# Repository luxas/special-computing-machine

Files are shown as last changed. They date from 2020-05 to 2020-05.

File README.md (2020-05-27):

# special-computing-machine
Let's make a Raspberry Pi cluster similar to real data centers!

# 3D models
The 3D model files in [hardware/models](hardware/models) include the following models by external authors, licensed for non-commercial use from [GrabCAD](https://grabcad.com).

 - [Raspberry Pi 4 Model B](https://grabcad.com/library/raspberry-pi-4-model-b-1) by [Hasanain Shuja](https://grabcad.com/hasanain.shuja-1)
 - [Intel 2.5" SSD 520 Series](https://grabcad.com/library/intel-2-5-ssd-520-series-1) by [Kevin Yu](https://grabcad.com/kevin.yu-7)

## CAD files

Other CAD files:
hardware/models/CU_Tray.step

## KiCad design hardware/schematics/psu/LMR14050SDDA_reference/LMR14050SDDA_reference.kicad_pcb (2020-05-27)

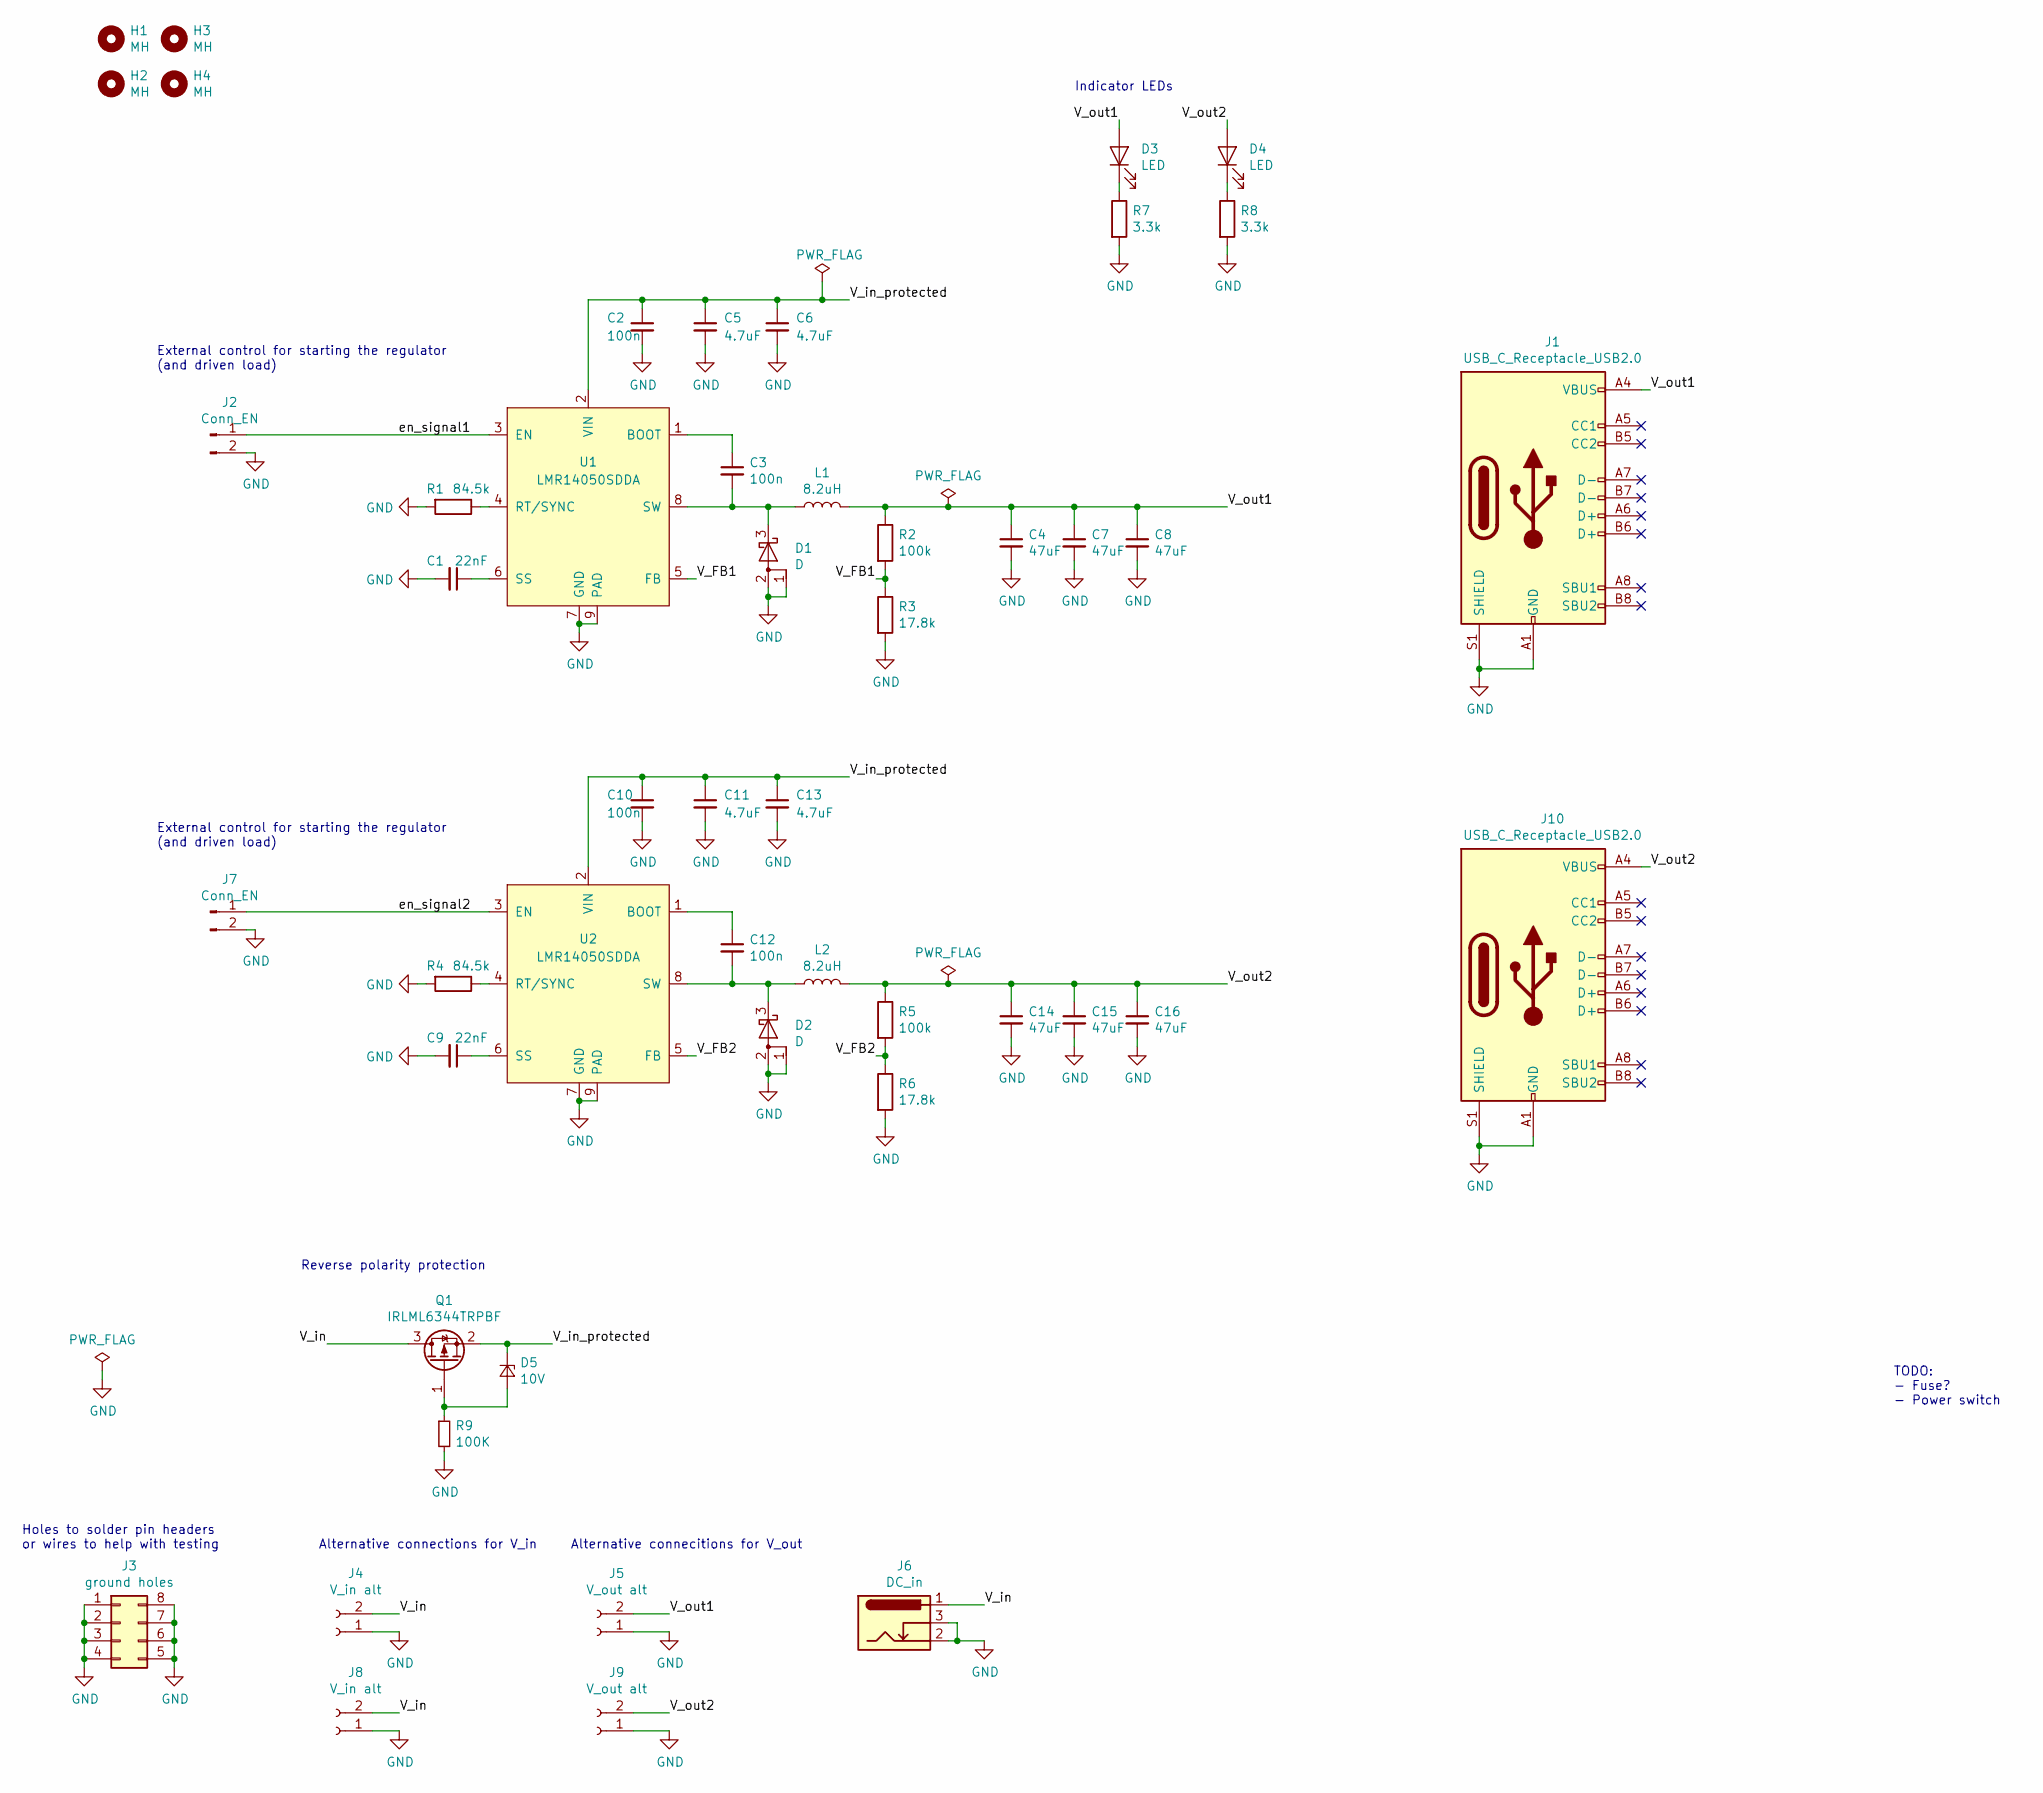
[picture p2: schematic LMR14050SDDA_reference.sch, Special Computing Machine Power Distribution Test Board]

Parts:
C1, C9: 22nF; C_0603_1608Metric
C2, C3, C10, C12: 100n; C_0603_1608Metric
C4, C7, C8, C14, C15, C16: 47uF; C_1210_3225Metric
C5, C6, C11, C13: 4.7uF; C_1206_3216Metric
D1, D2: D; TO-277A
D3, D4: LED; LED_0805_2012Metric
D5: 10V; D_SOD-323
H1, H2, H3, H4: MH; MountingHole_3.2mm_M3
J1, J10: USB_C_Receptacle_USB2.0; USB_C_Receptacle_HRO_TYPE-C-31-M-12
J2, J7: Conn_EN; PinHeader_1x02_P2.54mm_Vertical
J3: ground holes; PinHeader_2x04_P2.54mm_Vertical
J4, J8: V_in alt; TerminalBlock_bornier-2_P5.08mm
J5, J9: V_out alt; TerminalBlock_bornier-2_P5.08mm
J6: DC_in; BarrelJack_Wuerth_6941xx301002
L1, L2: 8.2uH; L_Wuerth_WE-PD-Typ-LS
Q1: IRLML6344TRPBF; SOT-23
R1, R4: 84.5k; R_0603_1608Metric
R2, R5: 100k; R_0603_1608Metric
R3, R6: 17.8k; R_0603_1608Metric
R7, R8: 3.3k; R_0805_2012Metric
R9: 100K; R_0603_1608Metric
U1, U2: LMR14050SDDA; Texas_HSOP-8-1EP_3.9x4.9mm_P1.27mm_ThermalVias

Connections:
/V_FB1: R2.2, R3.1, U1.5 (FB)
/V_FB2: R5.2, R6.1, U2.5 (FB)
/V_in: J4.2, J6.1, J8.2, Q1.3 (D)
/V_in_protected: C2.1, C5.1, C6.1, C10.1, C11.1, C13.1, D5.1 (K), Q1.2 (S), U1.2 (VIN), U2.2 (VIN)
/V_out1: C4.1, C7.1, C8.1, D3.2 (A), J1.A4 (VBUS), J1.A9 (VBUS), J1.B4 (VBUS), J1.B9 (VBUS), J5.2, L1.2, R2.1
/V_out2: C14.1, C15.1, C16.1, D4.2 (A), J9.2, J10.A4 (VBUS), J10.A9 (VBUS), J10.B4 (VBUS), J10.B9 (VBUS), L2.2, R5.1
/en_signal1: J2.1, U1.3 (EN)
/en_signal2: J7.1, U2.3 (EN)
GND: C1.2, C2.2, C4.2, C5.2, C6.2, C7.2, C8.2, C9.2, C10.2, C11.2, C13.2, C14.2, C15.2, C16.2, D1.1 (A), D1.2 (A), D2.1 (A), D2.2 (A), J1.A1 (GND), J1.A12 (GND), J1.B1 (GND), J1.B12 (GND), J1.S1 (SHIELD), J2.2, J3.1, J3.2, J3.3, J3.4, J3.5, J3.6, J3.7, J3.8, J4.1, J5.1, J6.2, J6.3, J7.2, J8.1, J9.1, J10.A1 (GND), J10.A12 (GND), J10.B1 (GND), J10.B12 (GND), J10.S1 (SHIELD), R1.2, R3.2, R4.2, R6.2, R7.2, R8.2, R9.2, U1.7 (GND), U1.9 (PAD), U2.7 (GND), U2.9 (PAD)
unnamed: C1.1, U1.6 (SS)
unnamed: C3.1, U1.1 (BOOT)
unnamed: C3.2, D1.3 (K), L1.1, U1.8 (SW)
unnamed: C9.1, U2.6 (SS)
unnamed: C12.1, U2.1 (BOOT)
unnamed: C12.2, D2.3 (K), L2.1, U2.8 (SW)
unnamed: D3.1 (K), R7.1
unnamed: D4.1 (K), R8.1
unnamed: D5.2 (A), Q1.1 (G), R9.1
unnamed: R1.1, U1.4 (RT/SYNC)
unnamed: R4.1, U2.4 (RT/SYNC)

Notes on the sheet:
External control for starting the regulator (and driven load)
Holes to solder pin headers or wires to help with testing
Alternative connections for V_in
Alternative connecitions for V_out
TODO: - Fuse? - Power switch
Indicator LEDs
Reverse polarity protection

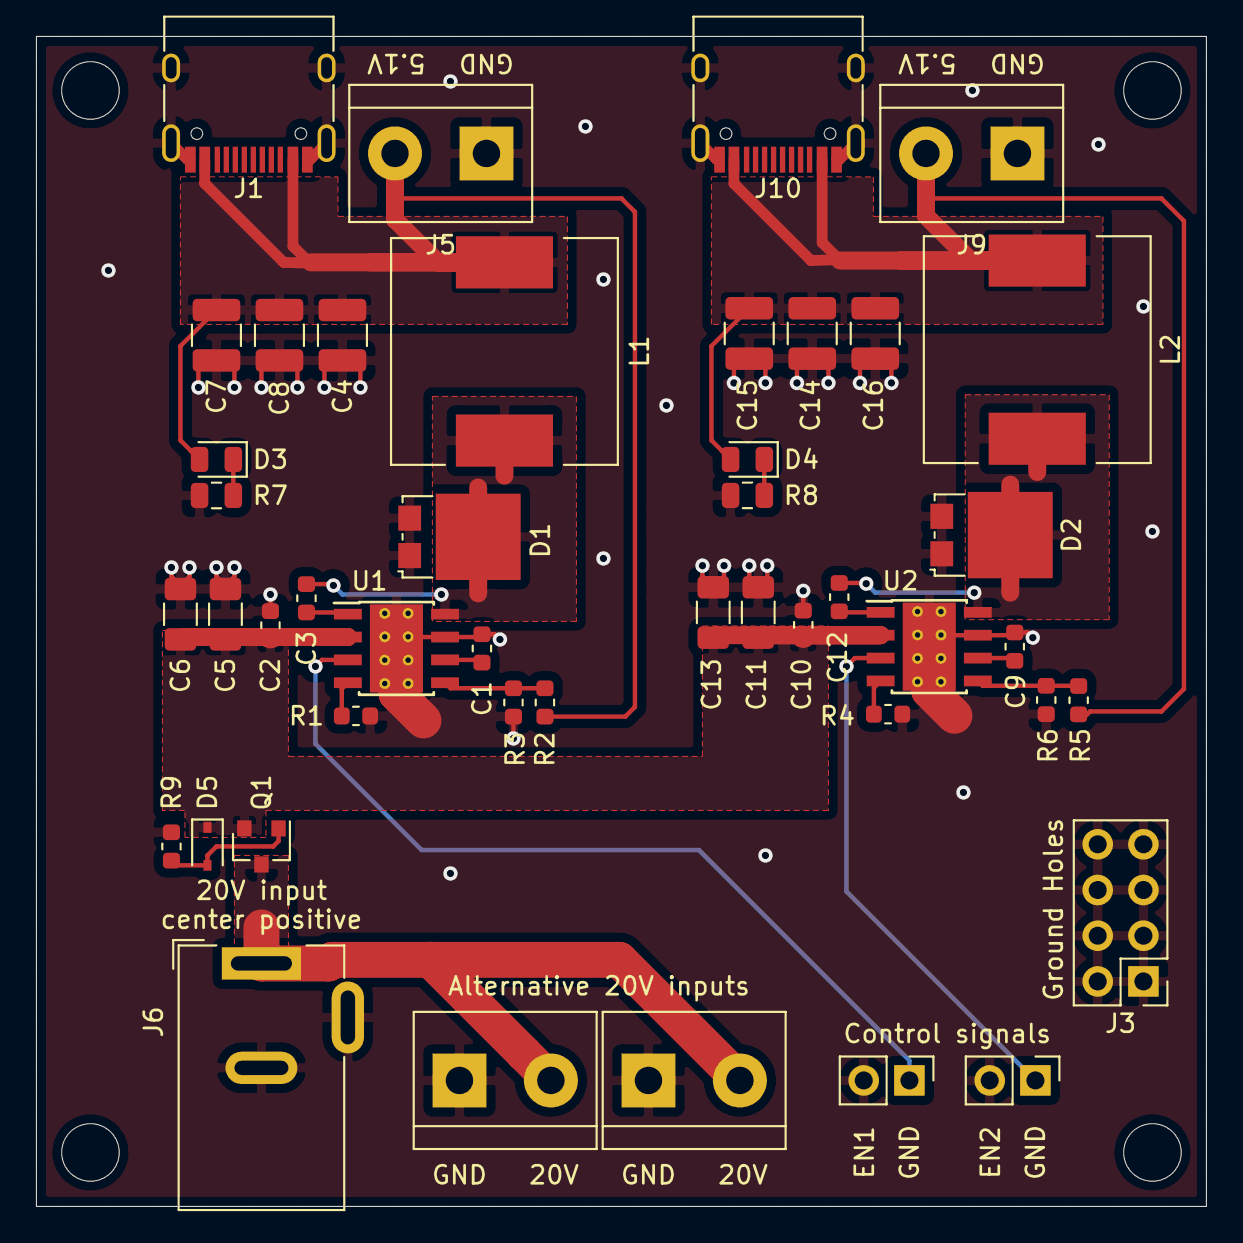
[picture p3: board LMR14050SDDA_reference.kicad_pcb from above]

Board: 2 copper layers, 65.0 x 65.0 mm, 49 parts (0 on the bottom side), 20 nets.

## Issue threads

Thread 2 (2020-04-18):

Select peripheral component values for LMR14050 buck regulator

VerkkuUkkeli, 2020-04-18:
Requirements:

* V_in = ~20V
* V_out = 5.1V
* I_out = 3A

Data sheet: https://www.ti.com/lit/ds/symlink/lmr14050.pdf

## TODO
* Feedback resistor network
  * [x] R_FBT = 100k [digikey](https://www.digikey.fi/product-detail/fi/stackpole-electronics-inc/RMCF0603FT100K/RMCF0603FT100KCT-ND/1943118)
  * [x] R_FBB = 17.4k [digikey](https://www.digikey.fi/product-detail/fi/stackpole-electronics-inc/RMCF0603FT17K4/RMCF0603FT17K4CT-ND/2417949)
* [x] R_T = 84.5k [digikey](https://www.digikey.fi/product-detail/fi/panasonic-electronic-components/ERJ-3EKF8452V/P84-5KHCT-ND/198530)
* [x] C_in [digikey](https://www.digikey.fi/product-detail/fi/kemet/C1206C475K5RACTU/399-11685-1-ND/5119828) x2 in series (Also add a generic 100nF decoupling capacitor with appropriate voltage range close the the chip power pin.)
* [x] C_out [digikey](https://www.digikey.fi/product-detail/fi/taiyo-yuden/EMK325BJ476MM-P/587-5436-1-ND/7067112) x3 in series
* [x] C_boot = 0.1uF [digikey](https://www.digikey.fi/product-detail/fi/yageo/CC0603KRX7R8BB104/311-1341-1-ND/2103125)
* [x] C_ss = 22 nF [digikey](https://www.digikey.fi/product-detail/fi/kemet/C0603C223K5RACTU/399-1280-1-ND/416056)
* [x] L = 8.2uH [digikey](https://www.digikey.fi/product-detail/fi/w%C3%BCrth-elektronik/744771008/732-1207-1-ND/1639268)
* [x] D [digikey](https://www.digikey.fi/product-detail/fi/stmicroelectronics/STPS1230SF/497-18303-1-ND/9696997)

## IO connectors
* [x] V_out to raspi [digikey](https://www.digikey.fi/product-detail/fi/gct/USB4085-GF-A/2073-USB4085-GF-ACT-ND/9859733)
* [x] V_in to Laptop Charger [digikey](https://www.digikey.fi/product-detail/fi/w-rth-elektronik/694106301002/732-5930-ND/5047522)

## Protection circuitry
Reverse polarity protection using a P-MOSFET
* [x] P-FET for reverse polarity protection [digikey](https://www.digikey.fi/product-detail/fi/infineon-technologies/IRLML6344TRPBF/IRLML6344TRPBFCT-ND/2538168)
* [x] 10V zener [digikey](https://www.digikey.fi/product-detail/fi/on-semiconductor/MM3Z10VST1G/MM3Z10VST1GOSCT-ND/687054)
* A generic 100k 0603 resistor

VerkkuUkkeli, 2020-04-18:
## Notes
By using feedback resistor values given in the data sheet example, we get a bit over 5V output at 5A. It is recommended
to use 1% tolerance or better and temperature coefficient of 100 ppm or lower divider resistors.

The switching frequency should not matter at the moment, so we can also use the values for 300kHz from the example application. This can be changed in the future if EMC issues arise.

Soft start time does not seem important for this application, using example values.

VerkkuUkkeli, 2020-04-22:
The design has been finished and documented to this issue.

Closed 2020-04-22.

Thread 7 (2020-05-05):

Design revision 2 of Power Delivery Test Board

VerkkuUkkeli, 2020-05-05:
Fix bugs in rev 1.
* [x] Fix silkscreen labels for enable signal and ground pairs
* [ ] Select a proper P-Channel FET for reverse polarity protection and see if the schematic needs to be modified (currently selected components was actually a N-Channel FET)
* [ ] Use hand soldering pads for some hard do solder components
  - Inductor
  - Power diode
  - Big capacitors

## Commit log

2020-04-18 WIP add work in progress buck converter schematic
    [LMR14050SDDA_reference.kicad_pcb, LMR14050SDDA_reference.sch]
2020-04-22 WIP Add power distribution test board rev 1.
    [LMR14050SDDA_reference.kicad_pcb, LMR14050SDDA_reference.sch]
2020-04-22 Add schematic information.
    [LMR14050SDDA_reference.sch]
2020-04-24 Final changes for ordering.
    [LMR14050SDDA_reference.kicad_pcb, LMR14050SDDA_reference.sch]
2020-04-24 Change USB C receptacle to a component that's in stock.
    [LMR14050SDDA_reference.kicad_pcb, LMR14050SDDA_reference.sch]
2020-05-04 Added and removed buttons
2020-05-05 Add one fake "SPI" implementation over PTY UART/serial
2020-05-09 Add interactive button. The button does not send proper request yet.
2020-05-27 Add sample demo page for interactive HTML for inspiration for the web UI
2020-05-27 Add the STEP file for the compute unit tray design
    [CU_Tray.step]
2020-05-27 Move place of the PSU source code
    [LMR14050SDDA_reference.kicad_pcb, LMR14050SDDA_reference.sch]
